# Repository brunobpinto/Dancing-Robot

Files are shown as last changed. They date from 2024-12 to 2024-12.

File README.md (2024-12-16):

Dancing-Robot-Banner

# Dancing Robot  
This project was developed as the final activity for the Microcontrollers Project class at PUC-Rio, Brazil. It showcases the integration of Arduino and MediaPipe to create a humanoid dancing robot that mimics human movements. The project was conceived as an idea aligned with this year's class theme, Interactive Art.  

## Video  
Watch the robot in action in the video below:

https://github.com/user-attachments/assets/82b7757a-404e-4159-b0a3-cdb6346fa5df

## Features  
- Humanoid robot capable of imitating human movements.  
- Motion capture powered by MediaPipe for precise tracking.  
- Controlled via Arduino, ensuring smooth and responsive movements.  
- Fully 3D-printed components for a customizable and modular design.  
- Themed around Interactive Art, blending technology and creativity.  
<br><br>
## Getting Started  

### Hardware Requirements  
- Arduino microcontroller (e.g., Arduino Mega or Uno).  
- 12 Servo motors (SG90 and MG90S models).
- 16-Channel 12-bit PWM and Servo Shield for Arduino
- Power supply for the servos and Arduino.  
- Camera for motion capture (any standard webcam, including built-in laptop cameras).
- Structure and pole to securely hold the robot in the air during operation.
- Structural components: 3D-printed parts (see below).
  
> [!WARNING]
> While the Arduino Uno may work, it is recommended to use an Arduino Mega due to its larger SRAM (8 KB vs. 2 KB on the Uno), which provides better performance and stability for memory-intensive tasks.

### Software Requirements  
- Arduino IDE for microcontroller programming.  
- Python 3.8 or later. 

### 3D Printed Files  
All 3D-printed files can be found in the `/3D_Files` directory.  

> [!TIP]
> Since the 3D files of the robot are symmetrical, you can simply open the SLDPRT files and mirror them to create both sides of the robot. Afterward, save the mirrored parts as STL files and you're ready to print! 
<div>‎</div>

## Installation  
### Setup Arduino:
   - Connect the servos to the PWM Servo Shield board.
   - Install the [Adafruit-PWM-Servo-Driver-Library](https://github.com/adafruit/Adafruit-PWM-Servo-Driver-Library)
   - Upload the provided Arduino code using the Arduino IDE.  

### Install Dependencies:
   - To install the Python dependencies, run the following command:  
     ```bash
     pip install -r requirements.txt
     ```  

### Arduino COM Settings:
Before running the project, make sure to correctly configure the Arduino's serial port. The serial port may vary depending on the operating system and the connection to the Arduino.
1. Open the main Python code file, main.py.
2. Locate the following code snippet:
    ```python
    try:
    arduino = serial.Serial("COM5", baudrate=9600)  # Change port according to your device
    ```
3. Replace **'COM5'** with the serial port of your Arduino.

### 3D Printing and Assembly Components:
   - Ensure that the robot is fully printed and assembled correctly, and that each servo is connected to the correct pwm port.  
   - And make sure the camera is connected and communicating with the code.

### Run the Project:
   - Execute the main.py file to start motion capture and servo control.  
<br><br>

## Usage
<div align="center">
  Interface 1
  Interface 2
</div>

## How It Works  
### Motion Capture and Pose Detection
- MediaPipe captures keypoints of human movements in real time via a camera.
- By analyzing the angles of the joints, it detects pre-programmed poses and synchronizes them with the music's rhythm.

### Beat Detection and Rhythm Syncing
- The Python code running on the computer detects the beat of the music and establishes the rhythm.
- This timing determines when each pose should be sent to the Arduino for execution.

### Servo Control and Synchronization
- The Arduino receives pose data via serial communication.
- It moves the robot’s servos in sync with the rhythm to perform the correct movements.

### 3D Printing and Assembly
- The robot's frame is constructed using 3D-printed parts.
- This provides a lightweight and modular structure for easy customization and assembly.

## Schematic  
Mr.Adam's Schematic

## Contributors  
We would like to extend our heartfelt thanks to everyone who contributed to the development of this project. Your support, ideas, and dedication were essential in bringing this robot to life.

- [@aurorarichaud](https://github.com/aurorarichaud)
- [@brunobpinto](https://github.com/brunobpinto)
- [@gvalente02](https://github.com/gvalente02)
- [@GabiScof](https://github.com/GabiScof)

Thank you all for your hard work and collaboration!

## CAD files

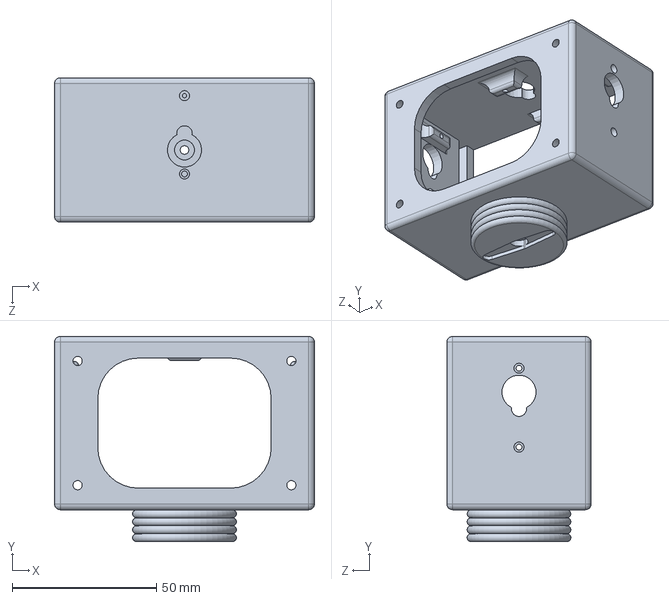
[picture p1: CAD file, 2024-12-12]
3D_Files/Adam_v1 Torso.SLDPRT
90.0 x 71.0 x 50.0 mm

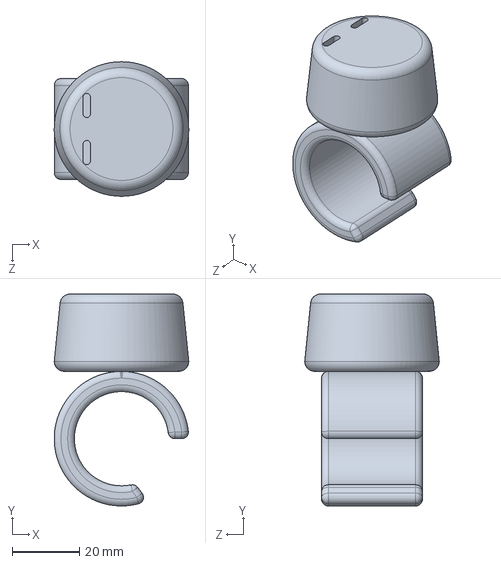
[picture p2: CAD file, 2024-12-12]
3D_Files/Adam_v1 Forearm.SLDPRT
40.0 x 63.0 x 40.0 mm

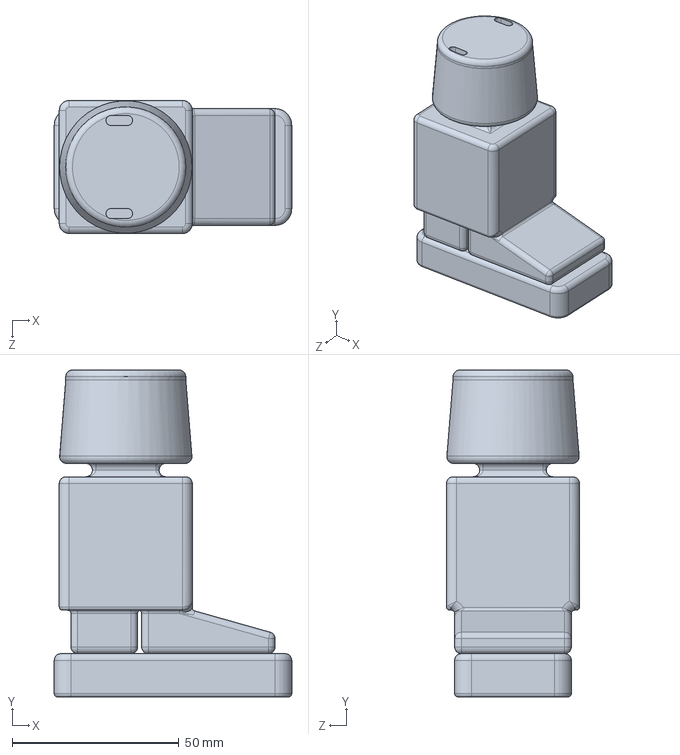
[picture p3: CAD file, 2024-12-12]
3D_Files/Adam_v1 Shin.SLDPRT
71.2 x 98.0 x 39.9 mm

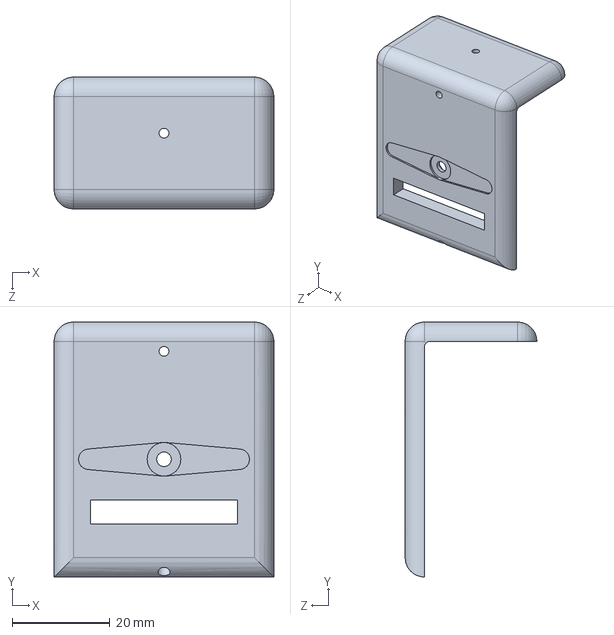
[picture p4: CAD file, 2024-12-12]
3D_Files/Adam_v1 Shoulder_Cap.SLDPRT
45.0 x 52.2 x 27.0 mm

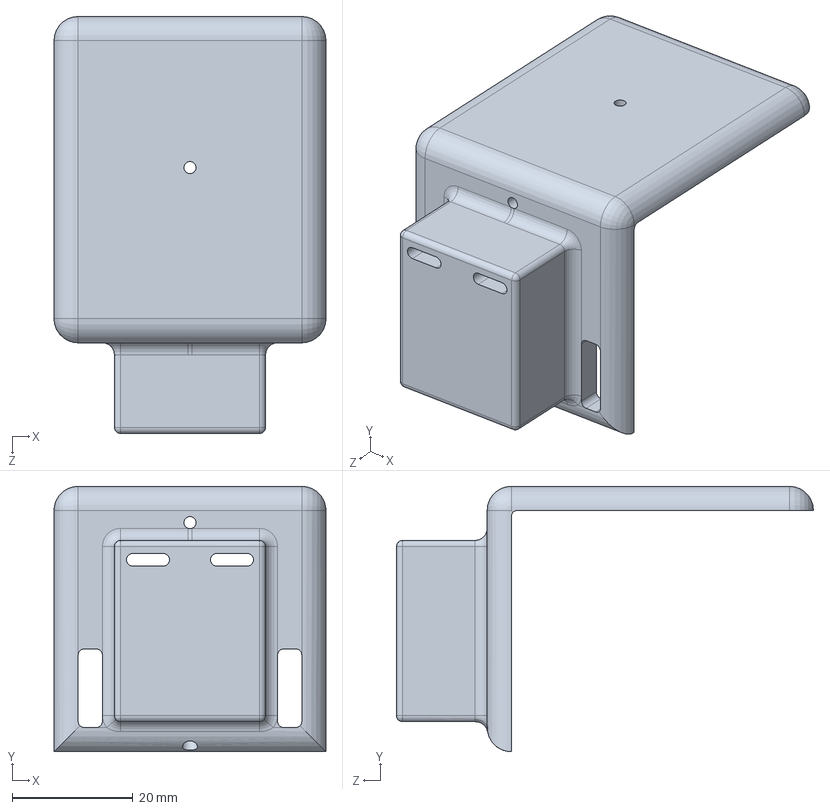
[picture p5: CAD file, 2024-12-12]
3D_Files/Adam_v1 Arm_Cap.SLDPRT
45.0 x 43.9 x 69.0 mm

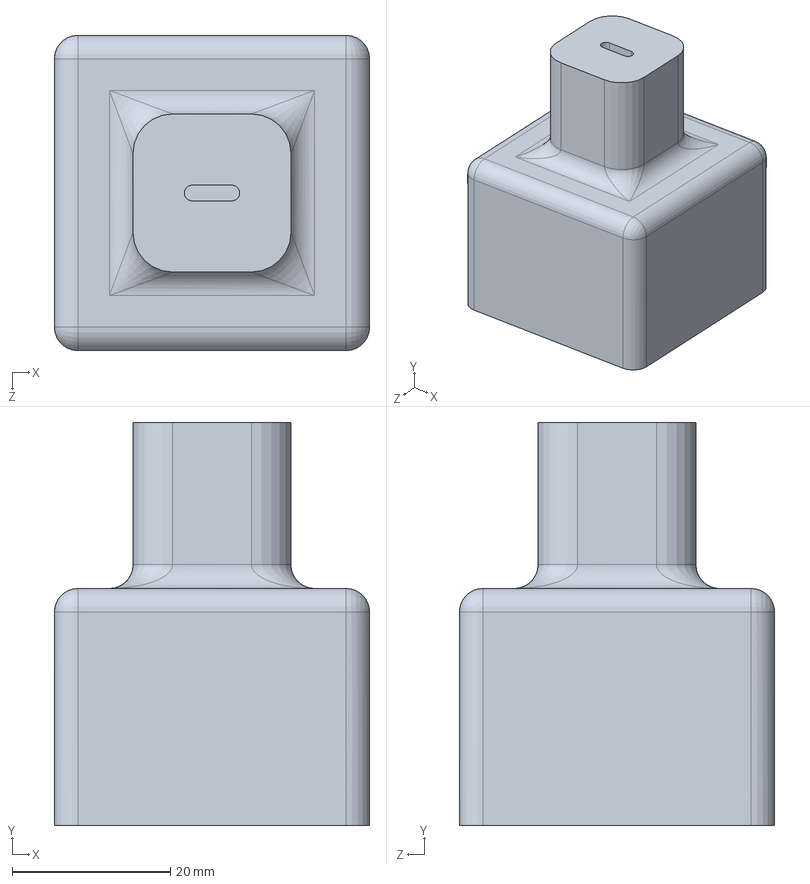
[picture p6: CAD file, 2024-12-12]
3D_Files/Adam_v1 Thigh.SLDPRT
39.9 x 51.0 x 39.9 mm

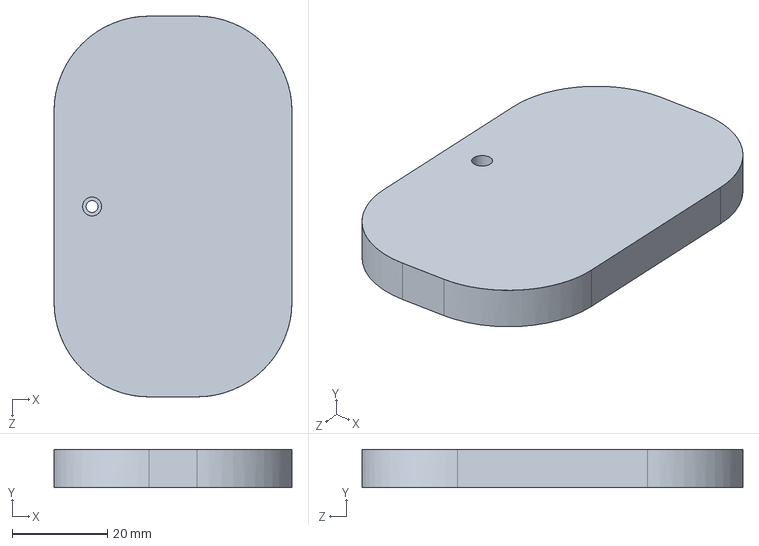
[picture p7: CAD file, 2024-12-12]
3D_Files/Adam_v1 Head_Cap.SLDPRT
50.0 x 8.00 x 80.0 mm

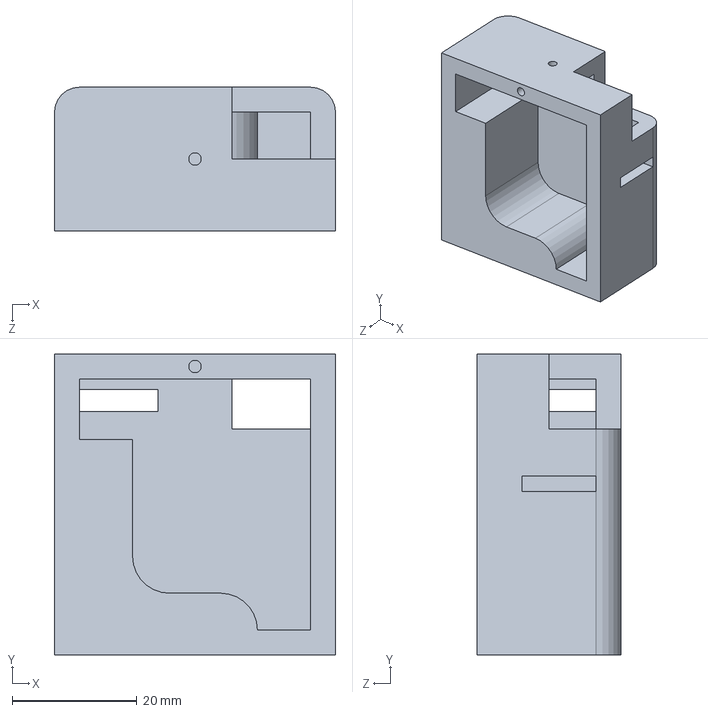
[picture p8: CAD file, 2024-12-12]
3D_Files/Adam_v1 Shoulder.SLDPRT
45.0 x 48.2 x 23.0 mm

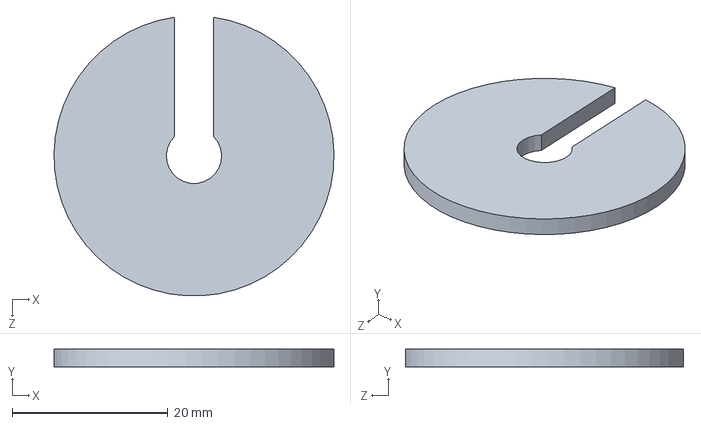
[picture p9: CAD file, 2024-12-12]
3D_Files/Adam_v1 Torso Extension.SLDPRT
36.0 x 2.30 x 35.8 mm

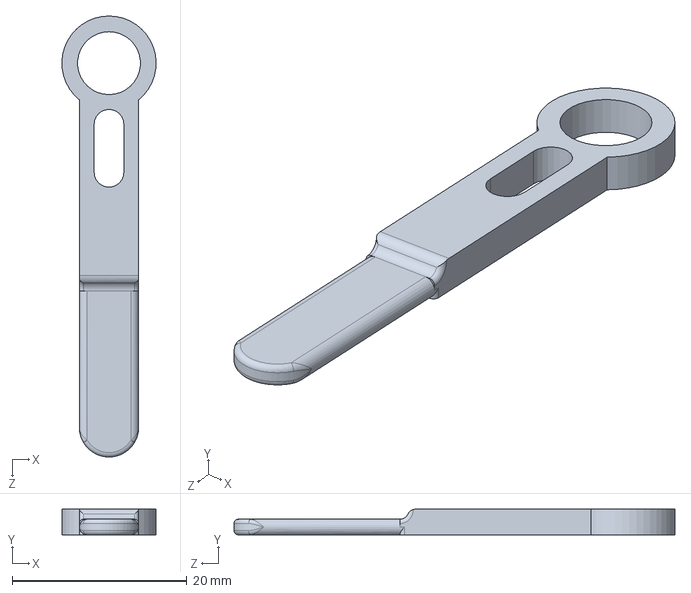
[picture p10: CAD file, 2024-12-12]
3D_Files/Adam_v1 Shin Extension.SLDPRT
10.8 x 2.95 x 50.5 mm

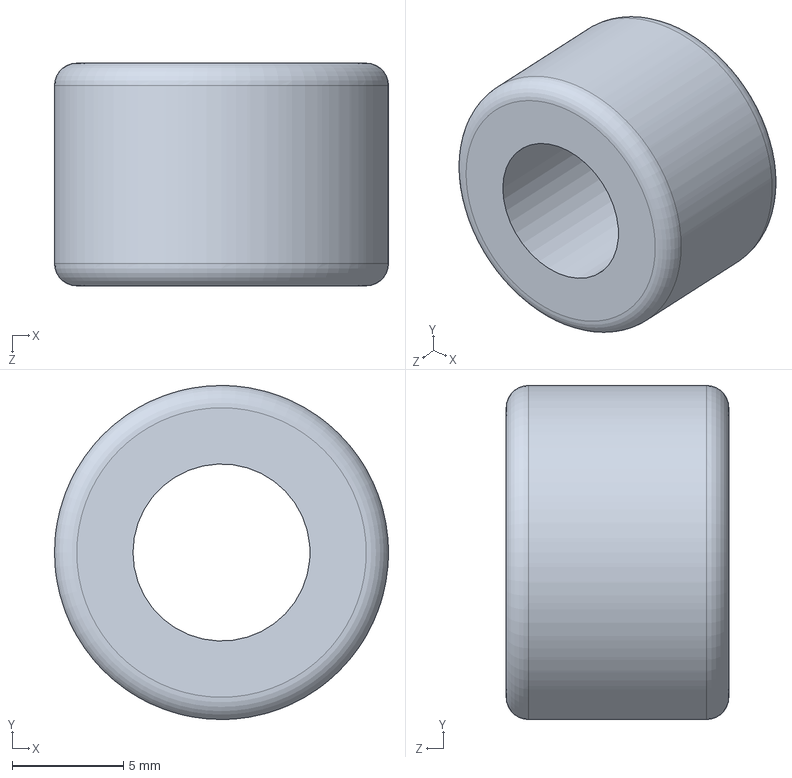
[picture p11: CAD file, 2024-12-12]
3D_Files/Adam_v1 Gripper Extension.SLDPRT
15.0 x 15.0 x 10.0 mm

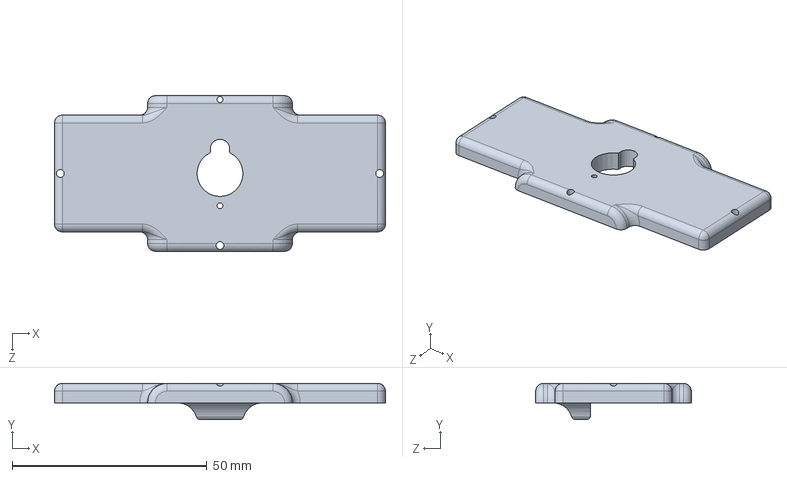
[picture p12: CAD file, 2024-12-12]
3D_Files/Adam_v1 Hip_Cap.SLDPRT
85.0 x 9.30 x 40.0 mm

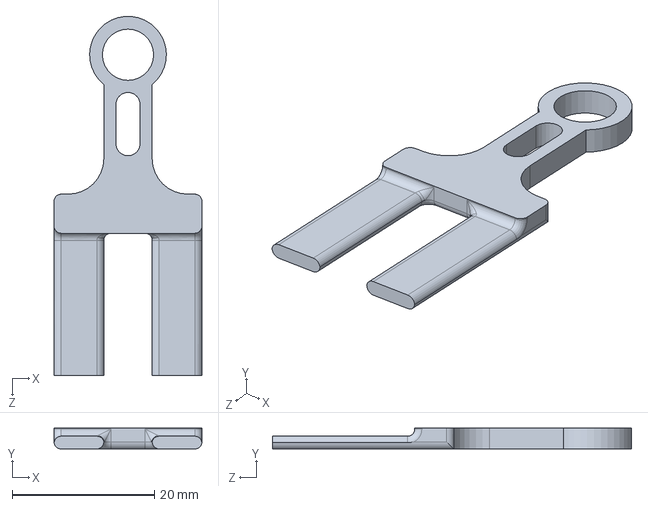
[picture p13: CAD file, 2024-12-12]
3D_Files/Adam_v1 Forearm Extension.SLDPRT
20.8 x 2.95 x 50.5 mm

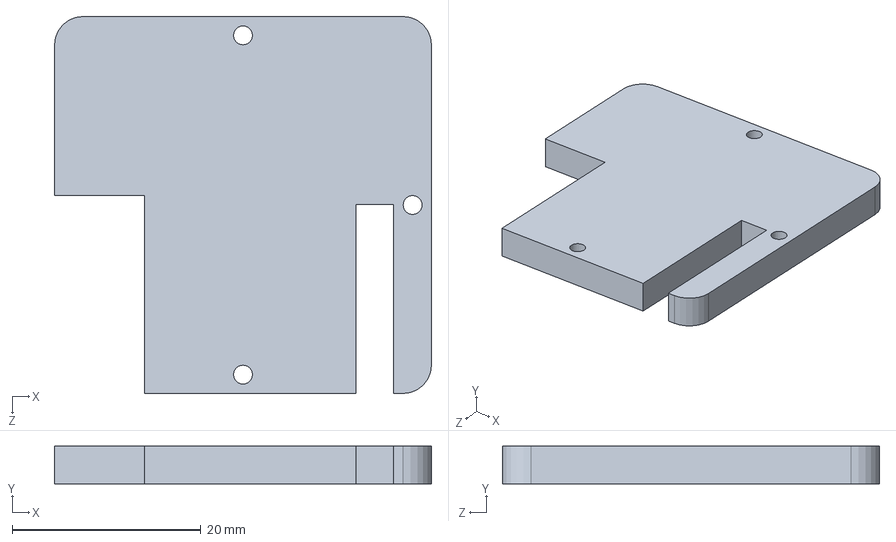
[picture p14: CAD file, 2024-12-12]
3D_Files/Adam_v1 Thigh_Cap.SLDPRT
39.9 x 4.00 x 39.9 mm

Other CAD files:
3D_Files/Adam_v2 Thigh Extension.SLDPRT
3D_Files/Adam_v1 Arm.SLDPRT
3D_Files/Adam_v1 Torso_Cap.SLDPRT
3D_Files/Adam_v1 Hip.SLDPRT
3D_Files/Adam_v1 Arm Extension.SLDPRT
3D_Files/Adam_v1 Head.SLDPRT
3D_Files/Adam_v1 Thigh Extension.SLDPRT

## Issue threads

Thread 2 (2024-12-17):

The following tasks could improve the project

brunobpinto, 2024-12-17:
### The following tasks could improve the project:
- [ ] Finish the polished Python interface as shown in the Figma prototype.
- [ ] Adjust how poses are displayed in the camera.
- [ ] Remove unnecessary code from the Motion Capture script.
- [ ] Translate the Arduino and Python code into English.
- [ ] Fix the servos that are not working in the physical robot.
- [ ] Refactor the Python code to ensure it is clean and well-written.
- [ ] Organize the 3D Files folder into respective subfolders.
- [ ] Create an assembly, and mirror parts to include both sides in the repository.
- [ ] Add STL files to the 3D Files folder.
- [ ] Create a tutorial and showcase video for the project.
- [ ] Verify and finish Schematic.
- [ ] Update the README.md, including a Usage section.
- [ ] Finally, test the updated code to ensure it works correctly.

### Interface Mockup
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

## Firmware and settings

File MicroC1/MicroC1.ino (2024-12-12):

#include <Adafruit_PWMServoDriver.h>
#include <stdio.h>
#include "Funcoes.h"
#include "Movimentos.h"

#define NUM_DANCAS 3

// Instancia o driver com o endereço padrão (0x40)
Adafruit_PWMServoDriver pwm = Adafruit_PWMServoDriver();

// Cria uuma Lista de Structs do tipo Danca
Danca dancas[NUM_DANCAS];   // Inicializando um array de n danças

void setup() {
  // Inicializa a Comunicação Serial
  Serial.begin(9600);
  Serial.println("=======>>> Mr.Adam foi inicializado <<<=======\n");

  // Inicializa o Shield de Servos(PWM)
  pwm.begin();
  pwm.setPWMFreq(50); // Frequência de 50 Hz para servos

  // Inicializa os Structs com os dados dos movimentos
  inicializarDancas(dancas);  // Funcao para preencher o array dancas

  // Exibir todas as danças na Serial
  exibirDancas(dancas, NUM_DANCAS); 

  // Ângulos Iniciais do Robô
  resetarRobo();
}

void loop() {
  // Verificação de Comandos na Serial
  if (Serial.available() > 0) {   
    String texto = Serial.readStringUntil('\n');    
    texto.trim();
    
    Serial.println(texto);

    if (texto == "Resetar") {         
      resetarRobo(); // Resetar robô para Ângulos Iniciais
    }

    if (texto == "Batida") {  
      moverPadrao(); // Função para mexer a cabeca sempre no ritmo da Batida
    }

    if (texto.startsWith("Teste")) {             // Exemplo: Teste 1 180 -> Faz o servoCabeça ir para o ângulo 180°  
      String indiceStr = texto.substring(6, 8);  // Pega o índice do Servo Motor desejado
      String anguloStr = texto.substring(8);     // Define o ângulo desejado
      int indice = indiceStr.toInt();
      int angulo = anguloStr.toInt();
      testarServo(indice, angulo);  
    }

    if (texto.startsWith("Movimento")) {            // Exemplo: Movimento leg01 arm01
      String dancaLeg = texto.substring(10, 15);
      String dancaArm = texto.substring(16, 21);  
      realizarDanca(dancas, dancaArm, true);        // Movimento do Braco
      realizarDanca(dancas, dancaLeg, false);       // Movimento da Perna
    }
    
  }

}

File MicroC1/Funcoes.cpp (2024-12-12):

#include <Adafruit_PWMServoDriver.h>
#include <Arduino.h>
#include <stdio.h>
#include "Funcoes.h"
#include "Movimentos.h"

// Definição de Variáveis
#define SERVO_MIN 150 // Pulso mínimo (em microsegundos) para 0 graus
#define SERVO_MAX 600 // Pulso máximo (em microsegundos) para 180 graus
#define TAXA 0.3      // Taxa da velocidade dos movimentos do robo
#define NUM_SERVOS 12 // Número de Servos no Robo
#define NUM_DANCAS 3  // Número de Dancas

// Definição de Variáveis Globais
int indicePadrao = 0;
int indiceBracos = 0;
int indicePernas = 0;
String anteriorBracos = "";
String anteriorPernas = "";

// Listas
String nomeServos[] = {"Antebraco Direito", "Torso", "Quadril Esquerdo", "Joelho Esquerdo", "Ombro Esquerdo", "Braco Esquerdo", "Antebraco Esquerdo", "Quadril Direito", "Joelho Direito", "Ombro Direito", "Braco Direito", "Cabeca"};
int listaAngulosIniciais[] = {60, 87, 45, 165, 155, 140, 25, 50, 70, 15, 75, 90};   // Lista de ângulos iniciais
int listaAngulos[]         = {60, 87, 45, 165, 155, 140, 25, 50, 70, 15, 75, 90};   // Lista de ângulos a ser modificada 

// Lista de ângulos mínimo e máximo
int listaMinMax[][2] = {
    {0, 80},    // Antebraço Direito
    {0, 180},   // Torso
    {30, 65},   // Quadril Esquerdo
    {75, 165},  // Joelho Esquerdo
    {0, 160},   // Ombro Esquerdo
    {75, 140},  // Braço Esquerdo
    {5, 95},    // Antebraço Esquerdo
    {25, 60},   // Quadril Direito
    {70, 150},  // Joelho Direito
    {10, 165},  // Ombro Direito
    {75, 140},  // Braço Direito
    {0, 180}    // Cabeça
};

// Função para Mover o Servo Suavemente para um Ângulo Específico
void moverServo(int numServo, int anguloDesejado, bool suave) {
  // Verificação dos ângulos
  anguloDesejado = constrain(anguloDesejado, listaMinMax[numServo][0], listaMinMax[numServo][1]);  // Limita os valores entre o Min e Max de cada servo

  // Movimento Direto para o angulo
  if (!suave) {
    int pulseMap = map(anguloDesejado, 0, 180, SERVO_MIN, SERVO_MAX);
    pwm.setPWM(numServo, 0, pulseMap);
  } 
  // Movimento Suave para o angulo com Comparacao na listaAngulos
  else {
    if (anguloDesejado > listaAngulos[numServo]) {    // Indo para um an gulo Maior que o Anterior
      for (float pulse = listaAngulos[numServo]; pulse <= anguloDesejado; pulse += TAXA) {
        int pulseMap = map(pulse, 0, 180, SERVO_MIN, SERVO_MAX);
        pwm.setPWM(numServo, 0, pulseMap);
      }
    }

    if (anguloDesejado < listaAngulos[numServo]) {    // Indo para um angulo Menor que o Anterior
      for (float pulse = listaAngulos[numServo]; pulse >= anguloDesejado; pulse -= TAXA) {
        int pulseMap = map(pulse, 0, 180, SERVO_MIN, SERVO_MAX);
        pwm.setPWM(numServo, 0, pulseMap);
      }
    }
  }
  
  listaAngulos[numServo] = anguloDesejado;
}

// Função para Testar um Único Servo pelo Índice dele
void testarServo(int indice, int angulo) {
  if (indice >= 0 && indice < NUM_SERVOS) {     // Verifica se o índice está dentro do limite dos servos
    moverServo(indice, angulo, true);           // Faz o write no servo correspondente ao índice suavemente
    Serial.print("Servo do(a) ");
    Serial.print(nomeServos[indice]);
    Serial.print(" foi ajustado para o ângulo: ");
    Serial.print(angulo);
    Serial.println("°");
  } else {
    Serial.println("Índice inválido!");
  }
}

// Função para Resetar o Robô
void resetarRobo() {
  // Colocar o Robô nos ângulos iniciais
  for (int indice = 0; indice < NUM_SERVOS; indice++) {   // Percorre a lista de Angulos Iniciais
    moverServo(indice, listaAngulosIniciais[indice], false);    // Vai diretamente para os angulos
  }
  Serial.println("Robô foi resetado para os ângulos iniciais");
  delay(500);  // Pausa para estabilizar os servos
}

// Função para inicializar as danças e seus movimentos
void inicializarDancas(Danca *dancas) {
    // Bracos para baixo mexendo o antebraco 
    strcpy(dancas[0].nome, "arm01");
    dancas[0].quantidadeServos = 6;
    dancas[0].quantidadeAngulos = 2;

    dancas[0].movimentos[0].servo = OMBRO_ESQUERDO;
    dancas[0].movimentos[0].angulos[0] = 0;
    dancas[0].movimentos[0].angulos[1] = 0; 

    dancas[0].movimentos[1].servo = OMBRO_DIREITO;
    dancas[0].movimentos[1].angulos[0] = 165;
    dancas[0].movimentos[1].angulos[1] = 165;

    dancas[0].movimentos[2].servo = BRACO_ESQUERDO;
    dancas[0].movimentos[2].angulos[0] = 75;
    dancas[0].movimentos[2].angulos[1] = 75;

    dancas[0].movimentos[3].servo = BRACO_DIREITO;
    dancas[0].movimentos[3].angulos[0] = 140;
    dancas[0].movimentos[3].angulos[1] = 140;

    dancas[0].movimentos[4].servo = ANTEBRACO_ESQUERDO;
    dancas[0].movimentos[4].angulos[0] = 60;
    dancas[0].movimentos[4].angulos[1] = 95;

    dancas[0].movimentos[5].servo = ANTEBRACO_DIREITO;
    dancas[0].movimentos[5].angulos[0] = 0;
    dancas[0].movimentos[5].angulos[1] = 30;

    // Bracos para cima de um lado para o outro 
    strcpy(dancas[1].nome, "arm02");
    dancas[1].quantidadeServos = 6;
    dancas[1].quantidadeAngulos = 2;

    dancas[1].movimentos[0].servo = OMBRO_ESQUERDO;
    dancas[1].movimentos[0].angulos[0] = 155;
    dancas[1].movimentos[0].angulos[1] = 155; 

    dancas[1].movimentos[1].servo = OMBRO_DIREITO;
    dancas[1].movimentos[1].angulos[0] = 15;
    dancas[1].movimentos[1].angulos[1] = 15;

    dancas[1].movimentos[2].servo = BRACO_ESQUERDO;
    dancas[1].movimentos[2].angulos[0] = 115;
    dancas[1].movimentos[2].angulos[1] = 140;

    dancas[1].movimentos[3].servo = BRACO_DIREITO;
    dancas[1].movimentos[3].angulos[0] = 75;
    dancas[1].movimentos[3].angulos[1] = 100;

    dancas[1].movimentos[4].servo = ANTEBRACO_ESQUERDO;
    dancas[1].movimentos[4].angulos[0] = 5;
    dancas[1].movimentos[4].angulos[1] = 60;

    dancas[1].movimentos[5].servo = ANTEBRACO_DIREITO;
    dancas[1].movimentos[5].angulos[0] = 20;
    dancas[1].movimentos[5].angulos[1] = 80;

    // Movimento de levantar as pernas 
    strcpy(dancas[2].nome, "leg01");
    dancas[2].quantidadeServos = 4;
    dancas[2].quantidadeAngulos = 2;

    dancas[2].movimentos[0].servo = QUADRIL_ESQUERDO;
    dancas[2].movimentos[0].angulos[0] = 65;
    dancas[2].movimentos[0].angulos[1] = 45; 

    dancas[2].movimentos[1].servo = QUADRIL_DIREITO;
    dancas[2].movimentos[1].angulos[0] = 50;
    dancas[2].movimentos[1].angulos[1] = 35;

    dancas[2].movimentos[2].servo = JOELHO_ESQUERDO;
    dancas[2].movimentos[2].angulos[0] = 125;
    dancas[2].movimentos[2].angulos[1] = 165;

    dancas[2].movimentos[3].servo = JOELHO_DIREITO;
    dancas[2].movimentos[3].angulos[0] = 70;
    dancas[2].movimentos[3].angulos[1] = 110;

}
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

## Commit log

2024-12-12 Add folder with 3D files for robot assembly
    Added a folder containing all the necessary 3D design files created in SolidWorks for the robot's assembly. These include structural components, joints, and other essential parts for 3D printing.
    [Adam v2 Extensão Servo Coxa.SLDPRT, Adam v2 Extensão torço.SLDPRT, Adam_v1 Antebraço.SLDPRT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]
2024-12-12 Add Arduino Code to Control Servos
2025-11-06 feature: Added Songs and Mediapipe Camera Code (Python)
